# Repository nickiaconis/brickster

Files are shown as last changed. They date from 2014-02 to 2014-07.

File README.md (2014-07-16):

BricksTer
=========

LEGO bricks controlled from terminal.

### Notice

[BricksTer has moved to BTbricks. Please follow this link for the list of new repositories.](https://github.com/BTbricks)

#### Android GUI (based on 8879 LEGO Power Functions Speed Remote Control)
<a href="http://www.youtube.com/watch?feature=player_embedded&v=Lc0wewJmFzc
" target="_blank">IMAGE ALT TEXT HERE</a>

#### Android GUI (based on 8885 LEGO Power Functions Remote Control)
<a href="http://www.youtube.com/watch?feature=player_embedded&v=7uIiopYaczg
" target="_blank">IMAGE ALT TEXT HERE</a>

#### Initial Prototype Demonstration
<a href="http://www.youtube.com/watch?feature=player_embedded&v=reglTOSkLqM
" target="_blank">IMAGE ALT TEXT HERE</a>

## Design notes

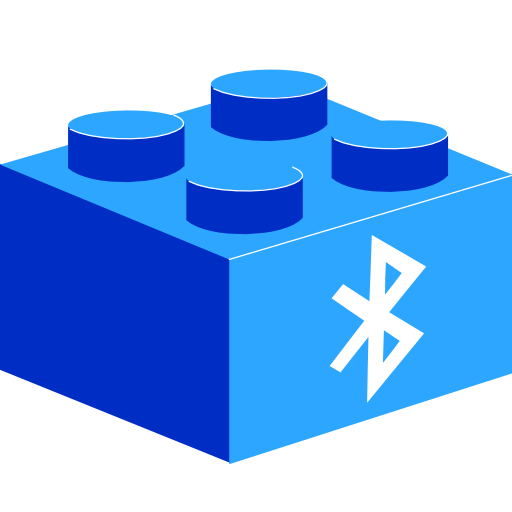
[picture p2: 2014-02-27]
android/ic_launcher-web.png

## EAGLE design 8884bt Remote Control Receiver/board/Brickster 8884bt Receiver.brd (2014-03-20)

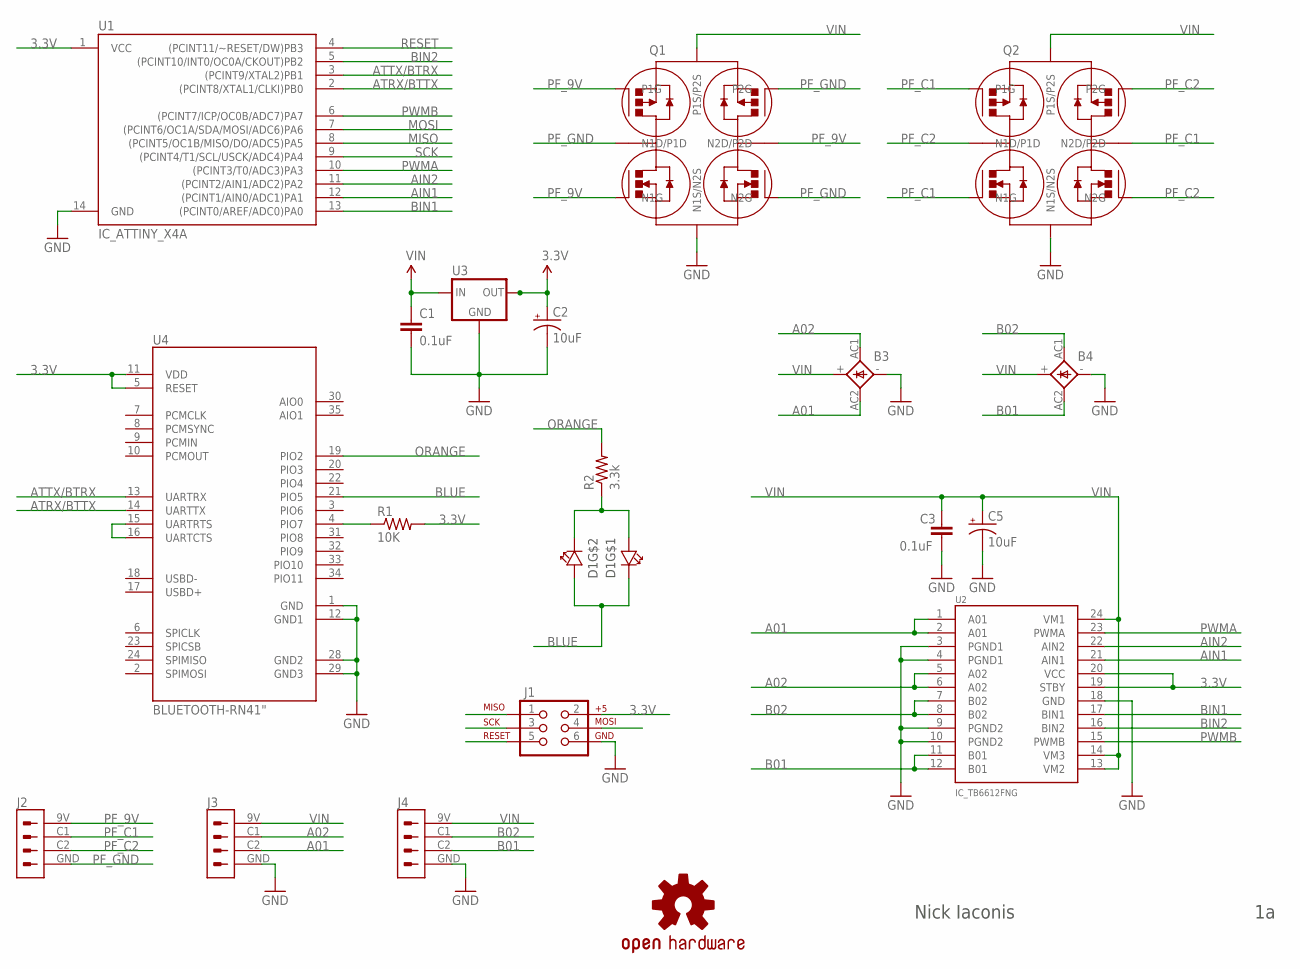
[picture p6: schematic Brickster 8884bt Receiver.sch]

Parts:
B3, B4: B_CDBHM240L-HF; MBS-2
C1, C3: 0.1uF; 0805
C2, C5: 10uF; 1206
D1: Blue/Orange; CHIP-LTST
J1: AVR_SPI_PRG_6NS; 2X3-NS
J2, J3, J4: CON_PF
LOGO1: OSHW-LOGOM; OSHW-LOGO-M
Q1, Q2: IC_FET_BRIDGESO8; SO8
R1: 10K; 0805
R2: 3.3k; 0805
U1: IC_ATTINY_X4A; 14S1
U2: IC_TB6612FNG; SSOP24
U3: IC_RT9164A; SOT223
U4: BLUETOOTH-RN41"; RN41

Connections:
3.3V: C2.1 (+), J1.2, R1.P$2 (2), U1.1 (VCC), U2.19 (STBY), U2.20 (VCC), U3.2 (OUT), U3.4, U4.5 (RESET), U4.11 (VDD)
A01: B3.AC2, J3.C2, U2.1 (A01), U2.2 (A01)
A02: B3.AC1, J3.C1, U2.5 (A02), U2.6 (A02)
AIN1: U1.12 ((PCINT1/AIN0/ADC1)PA1), U2.21 (AIN1)
AIN2: U1.11 ((PCINT2/AIN1/ADC2)PA2), U2.22 (AIN2)
ATRX/BTTX: U1.2 ((PCINT8/XTAL1/CLKI)PB0), U4.14 (UARTTX)
ATTX/BTRX: U1.3 ((PCINT9/XTAL2)PB1), U4.13 (UARTRX)
B01: B4.AC2, J4.C2, U2.11 (B01), U2.12 (B01)
B02: B4.AC1, J4.C1, U2.7 (B02), U2.8 (B02)
BIN1: U1.13 ((PCINT0/AREF/ADC0)PA0), U2.17 (BIN1)
BIN2: U1.5 ((PCINT10/INT0/OC0A/CKOUT)PB2), U2.16 (BIN2)
BLUE: D1.2, D1.3, U4.21 (PIO5)
GND: B3.-, B4.-, C1.P$2 (2), C2.2 (-), C3.P$2 (2), C5.2 (-), J1.6, J3.GND, J4.GND, Q1.P$3 (N1S/N2S), Q2.P$3 (N1S/N2S), U1.14 (GND), U2.3 (PGND1), U2.4 (PGND1), U2.9 (PGND2), U2.10 (PGND2), U2.18 (GND), U3.1 (GND), U4.1 (GND), U4.12 (GND1), U4.28 (GND2), U4.29 (GND3)
MISO: J1.1, U1.8 ((PCINT5/OC1B/MISO/DO/ADC5)PA5)
MOSI: J1.4, U1.7 ((PCINT6/OC1A/SDA/MOSI/ADC6)PA6)
unnamed: U4.15 (UARTRTS), U4.16 (UARTCTS)
unnamed: R1.P$1 (1), U4.4 (PIO7)
unnamed: D1.1, D1.4, R2.P$1 (1)
ORANGE: R2.P$2 (2), U4.19 (PIO2)
PF_9V: J2.9V, Q1.P$1 (N1G), Q1.P$6 (N2D/P2D), Q1.P$8 (P1G)
PF_C1: J2.C1, Q2.P$1 (N1G), Q2.P$6 (N2D/P2D), Q2.P$8 (P1G)
PF_C2: J2.C2, Q2.P$2 (N1D/P1D), Q2.P$4 (N2G), Q2.P$5 (P2G)
PF_GND: J2.GND, Q1.P$2 (N1D/P1D), Q1.P$4 (N2G), Q1.P$5 (P2G)
PWMA: U1.10 ((PCINT3/T0/ADC3)PA3), U2.23 (PWMA)
PWMB: U1.6 ((PCINT7/ICP/OC0B/ADC7)PA7), U2.15 (PWMB)
RESET: J1.5, U1.4 ((PCINT11/~RESET/DW)PB3)
SCK: J1.3, U1.9 ((PCINT4/T1/SCL/USCK/ADC4)PA4)
VIN: B3.+, B4.+, C1.P$1 (1), C3.P$1 (1), C5.1 (+), J3.9V, J4.9V, Q1.P$7 (P1S/P2S), Q2.P$7 (P1S/P2S), U2.13 (VM2), U2.14 (VM3), U2.24 (VM1), U3.3 (IN)

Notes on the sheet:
Nick Iaconis

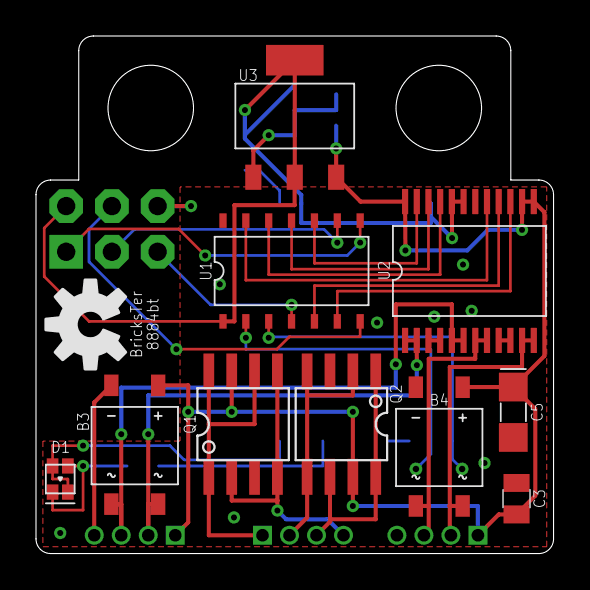
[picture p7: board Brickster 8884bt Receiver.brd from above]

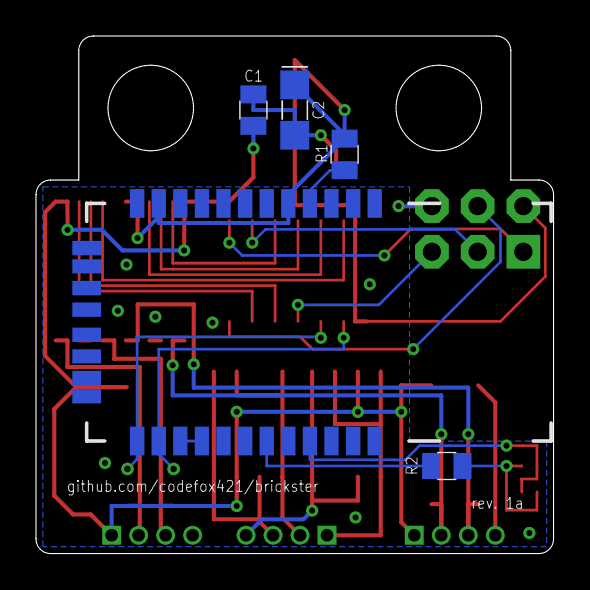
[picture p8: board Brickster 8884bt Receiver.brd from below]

Board: 2 copper layers, 28.8 x 28.8 mm, 20 parts (5 on the bottom side), 28 nets.

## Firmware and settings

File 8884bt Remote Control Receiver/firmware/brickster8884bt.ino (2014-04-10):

/*------------------------------------------------------------------------------
  The MIT License (MIT)

  Copyright (c) 2013 Nick Iaconis et al.
  
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
  THE SYSTEM IS PROVIDED "AS IS", WITHOUT WARRANTY OF ANY KIND, EXPRESS OR
  IMPLIED, INCLUDING BUT NOT LIMITED TO THE WARRANTIES OF MERCHANTABILITY,
  FITNESS FOR A PARTICULAR PURPOSE AND NONINFRINGEMENT. IN NO EVENT SHALL THE
  AUTHORS OR COPYRIGHT HOLDERS BE LIABLE FOR ANY CLAIM, DAMAGES OR OTHER
  LIABILITY, WHETHER IN AN ACTION OF CONTRACT, TORT OR OTHERWISE, ARISING FROM,
  OUT OF OR IN CONNECTION WITH THE SYSTEM OR THE USE OR OTHER DEALINGS IN THE
  SYSTEM.
------------------------------------------------------------------------------*/

/*------------------
  #### ATtiny84 ####
  ------------------
         ____       
  VCC  <|*   |> GND 
  IO10 <|    |> IO 0
  IO 9 <|    |> IO 1
  RST  <|    |> IO 2
  IO 8 <|    |> IO 3
  IO 7 <|    |> SCK 
  MOSI <|____|> MISO

  ------------------*/

/*----------------------------
  #### Swap Motor Drivers ####
  ----------------------------
  
  Regex:   ^( *)(.*tb6612fng)
  Replace: $1//$2
  
  Regex:   ^( *)//(.*drv8833)
  Replace: $1$2
  
  ----------------------------*/

#include <SoftwareSerial.h>
#define uSecCyc 870

// Motor control A
#define mcPin1A 1 // tb6612fng
#define mcPin2A 2 // tb6612fng
#define pwmPinA 3 // tb6612fng
//#define mcPin1A 9 // drv8833
//#define mcPin2A 10 // drv8833
//char pwmPinA = mcPin1A; // drv8833
#define maxA 28
char levelA = 0;
int pwmA = 0;

// Motor control B
#define mcPin1B 0 // tb6612fng
#define mcPin2B 8 // tb6612fng
#define pwmPinB 7 // tb6612fng
//#define mcPin1B 7 // drv8833
//#define mcPin2B 8 // drv8833
//char pwmPinB = mcPin1B; // drv8833
#define maxB 28
char levelB = 0;
int pwmB = 0;

// Channel A commands
#define maskA 83
#define upA 65    // A up         = A
#define downA 66  // A down       = B
#define brakeA 67 // A brake      = C
#define floatA 80 // A float      = P
#define ffwdA 81  // A full fwd   = Q
#define frevA 82  // A full rev   = R

// Channel B commands
#define maskB 108
#define upB 68    // B up         = D
#define downB 72  // B down       = H
#define brakeB 76 // B brake      = L
#define floatB 96 // B float      = `
#define ffwdB 100 // B full fwd   = d
#define frevB 104 // B full rev   = h

// Combine Channel A command with Channel B command using logical OR

// Software serial
#define rxPin 10 // tb6612fng
#define txPin 9 // tb6612fng
//#define rxPin 0 // drv8833
//#define txPin 1 // drv8833
#define baudRate 9600
SoftwareSerial softSerial(rxPin, txPin);

// Miscellanious
char incomingByte = 0;
char maskedByte = 0;
char serialRateLimiter = 0;
// int pwmLevels[8] = {0, 218, 326, 435, 544, 653, 761, 870};
int pwmLevels[29] = {0, 141, 168, 195, 222, 249, 276, 303, \
                      330, 357, 384, 411, 438, 465, 492, \
                      519, 546, 573, 600, 627, 654, 681, \
                      708, 735, 762, 789, 816, 843, 870};

// Function definitions
void comboMode(const char, char*, const char, const char, \
                const char, const char, const char, const char, \
                const char, const char, const char, const char);
void bitBangPwm(char, int, char, int);



/*----------------------------------------------------------------------------*/



void setup()
{
  // serial init
  softSerial.begin(baudRate);
  
  // channel A init
  pinMode(mcPin1A, OUTPUT);
  pinMode(mcPin2A, OUTPUT);
  pinMode(pwmPinA, OUTPUT);
  digitalWrite(mcPin1A, LOW);
  digitalWrite(mcPin2A, LOW);
  digitalWrite(pwmPinA, LOW);
  
  // channel B init
  pinMode(mcPin1B, OUTPUT);
  pinMode(mcPin2B, OUTPUT);
  pinMode(pwmPinB, OUTPUT);
  digitalWrite(mcPin1B, LOW);
  digitalWrite(mcPin2B, LOW);
  digitalWrite(pwmPinB, LOW);
  
  // bitbanged PWM init
  pwmA = pwmLevels[min(abs(levelA), maxA)];
  pwmB = pwmLevels[min(abs(levelB), maxB)];
}



void loop()
{
  // Handle serial communication
  //   - software serial interferes with PWM
  //   - limit to once every 8(?) loops
  if (!serialRateLimiter && softSerial.available() > 0)
  {
    // read incoming byte
    incomingByte = softSerial.read();
    

    // Direct PWM mode (fine resolution)
    if (incomingByte & 128) // 1xxx xxxx
    {
      // select proper output
      char* levelX = incomingByte & 64 ? &levelB : &levelA;
      int* pwmX = incomingByte & 64 ? &pwmB : &pwmA;
      if ((incomingByte & 63) < 29 || (incomingByte & 63) > 35)
      {
        // set the level
        *levelX = (incomingByte & 31) | (incomingByte & 32 ? 224 : 0);
        // set the motor control wires
        digitalWrite(incomingByte & 64 ? mcPin1B : mcPin1A, (*levelX > 0 ? HIGH : LOW));
        digitalWrite(incomingByte & 64 ? mcPin2B : mcPin2A, (*levelX < 0 ? HIGH : LOW));
      }
      else if ((incomingByte & 63) == 32) // xx10 0000 -> brake
      {
        // set the level
        *levelX = 0;
        // set the motor control wires
        digitalWrite(incomingByte & 64 ? mcPin1B : mcPin1A, HIGH);
        digitalWrite(incomingByte & 64 ? mcPin2B : mcPin2A, HIGH);
      }
      // notify sender
      softSerial.print(*levelX, DEC);
    }

    // Combo output mode
    else if (incomingByte & 64) // 01xx xxxx
    {
      // set channel A
      comboMode(incomingByte, &levelA, maxA, maskA, brakeA, floatA, \
                  upA, downA, ffwdA, frevA, mcPin1A, mcPin2A);
      // set channel B
      comboMode(incomingByte, &levelB, maxB, maskB, brakeB, floatB, \
                  upB, downB, ffwdB, frevB, mcPin1B, mcPin2B);
      // notify sender
      maskedByte = abs(levelB >> 2) + (levelB < 0 ? 8 : 0);
      maskedByte = (maskedByte << 4) + abs(levelA >> 2) + (levelA < 0 ? 8 : 0);
      softSerial.print(maskedByte, DEC);
    }
    
    // set the pwm
    pwmA = pwmLevels[min(abs(levelA), maxA)];
    //pwmPinA = levelA < 0 ? mcPin2A : mcPin1A; // drv8833
    pwmB = pwmLevels[min(abs(levelB), maxB)];
    //pwmPinB = levelB < 0 ? mcPin2B : mcPin1B; // drv8833
    
    // rate limit
    serialRateLimiter = 8;
  }
  
  // Bitbang the PWM signals
  bitBangPwm(pwmPinA, pwmA, pwmPinB, pwmB);
  
  // Decrement rate limiter
  if (serialRateLimiter)
    --serialRateLimiter;
  
}



/*----------------------------------------------------------------------------*/




void comboMode(const char incomingByte, char* levelX, const char maxX, \
                const char maskX, const char brakeX, const char floatX, \
                const char upX, const char downX, const char ffwdX, \
                const char frevX, const char mcPin1X, const char mcPin2X)
{
  maskedByte = incomingByte & maskX;
  // decode command
  if (maskedByte == brakeX || maskedByte == floatX)
  {
    *levelX = 0;
  }
  else if (maskedByte == upX)
  {
    if (*levelX >= 0)
    {
      *levelX = min((*levelX + 4) & ~3, maxX);
    }
    else
    {
      if (abs(*levelX) & 3)
        *levelX = -(abs(*levelX) & ~3);
      else
        *levelX += 4;
    }
  }
  else if (maskedByte == downX)
  {
    if (*levelX <= 0)
    {
      *levelX = -min((abs(*levelX) + 4) & ~3, maxX);
    }
    else
    {
      if (*levelX & 3)
        *levelX &= ~3;
      else
        *levelX -= 4;
    }
  }
  else if (maskedByte == ffwdX)
  {
    *levelX = maxX;
  }
  else if (maskedByte == frevX)
  {
    *levelX = -maxX;
  }

  // set the motor control wires
  digitalWrite(mcPin1X, (*levelX > 0 || maskedByte == brakeX ? HIGH : LOW));
  digitalWrite(mcPin2X, (*levelX < 0 || maskedByte == brakeX ? HIGH : LOW));
}



void bitBangPwm(char thePwmPinA, int pwmA, char thePwmPinB, int pwmB)
{
  // Bitbang the PWM signals
  // turn on both channels
  if (pwmA > 0)
    digitalWrite(thePwmPinA, HIGH);
  if (pwmB > 0)
    digitalWrite(thePwmPinB, HIGH);
  if (pwmA <= pwmB)
  {
    // pwmA is shorter
    if (pwmA > 0)
    {
      delayMicroseconds(pwmA);
      // channelA off
      digitalWrite(thePwmPinA, LOW);
    }
    // wait the difference
    if (pwmA != pwmB)
    {
      delayMicroseconds(pwmB - pwmA);
      // channelB off
      digitalWrite(thePwmPinB, LOW);
    }
    // finish out the cycle
    if (pwmB < uSecCyc)
      delayMicroseconds(uSecCyc - pwmB);
  }
  else
  {
    // pwmB is shorter
    if (pwmB > 0)
    {
      delayMicroseconds(pwmB);
      // channelB off
      digitalWrite(thePwmPinB, LOW);
    }
    // wait the difference
    if (pwmA != pwmB)
    {
      delayMicroseconds(pwmA - pwmB);
      // channelA off
      digitalWrite(thePwmPinA, LOW);
    }
    // finish out the cycle
    if (pwmA < uSecCyc)
      delayMicroseconds(uSecCyc - pwmA);
  }
}

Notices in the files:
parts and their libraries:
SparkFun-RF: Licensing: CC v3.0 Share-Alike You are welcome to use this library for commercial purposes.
